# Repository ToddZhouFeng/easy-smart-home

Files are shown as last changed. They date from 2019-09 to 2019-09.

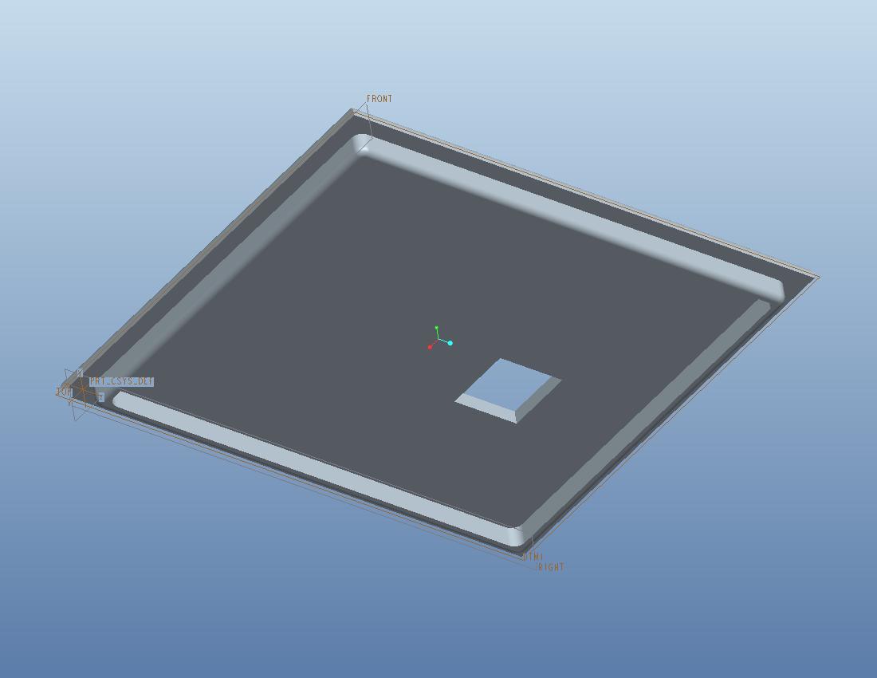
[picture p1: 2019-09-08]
example/auto AC remote control/3D model/cup/cup.jpg

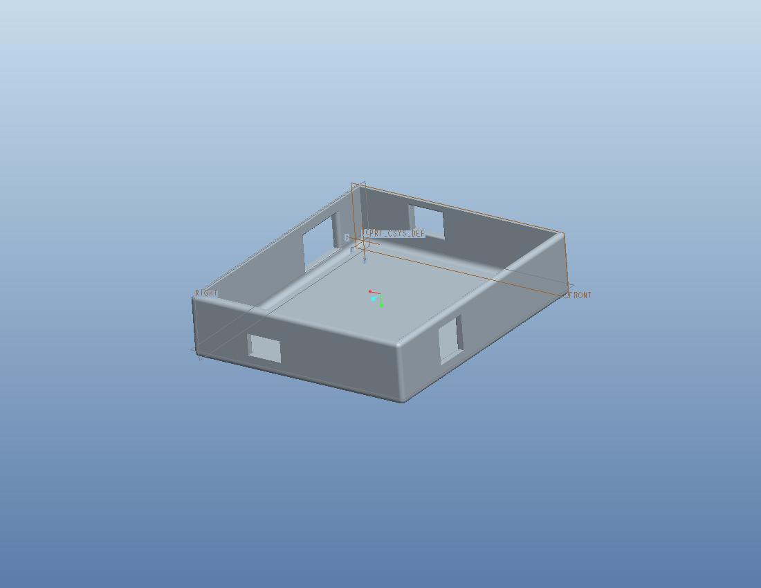
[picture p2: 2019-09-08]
example/auto AC remote control/3D model/shell/shell.jpg

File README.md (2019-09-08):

# easy-smart-home 轻智居
 This project aims to provide an easy solution for setting up  smart home in a affordable price.

该项目致力于提供便宜且易于设置的智能家居解决方案。

**Supported Device :**(for now)

**支持设备：**（目前）

* Arduino

# Structure 框架

* **Definition:**

  * **Master**：device that **can send instruction**

    **主机**：**可发送**指令的设备

  * **Slave**：device that **can's send instruction** but can receives instruction  

    **从机**：**不可发送**指令的设备，但可接收指令的设备

* **Single Line 单线：**

（如果显示不了，请前往[toddzhoufeng.github.io](https://toddzhoufeng.github.io)）

单主机单从机：

~~~sequence
Title: One Master One Slave
Master->Slave: Control
Slave-->Furniture: Control
~~~

* **Multiple Line 多线：**

单主机多从机：

```sequence
Title: One Master Multiple Slaves
Master->Slave1: Control
Master->Slave2: Control
Master->Slave3: Control
Slave3-->Furniture: Control
Slave2-->Furniture: Control
Slave1-->Furniture: Control 
```

多主机单从机：

```sequence
Title: Multiple Masters One Slave

participant Master1
participant Master2

Master1->Slave: Control
Master2->Slave: Control
Slave-->Furniture: Control
```

多主机多从机：

```sequence
Title: Multiple Masters Multiple Slave

participant Master1
participant Master2

Master1->Slave1: Control
Master2->Slave1: Control
Master1->Slave2: Control

Master2->Slave2: Control
Slave1-->Furniture: Control
Slave2-->Furniture: Control
```

# IR Protocol 红外编码

红外接收相比于蓝牙和网络的优势在于：

* 价格更便宜：红外接收管的价格为￥0.2/个
* 使用的引脚更少：仅需要1个
* 耗电量更小
* 等等

缺点在于：

* 对指向有一定要求
* 要求设备有开孔
* 无法做到远程操控
* 等等

目前来讲，红外比较适合受到自然条件（光、温）影响的智能设备，比如灯、窗帘、空调等，因为这些设备的位置比较固定，并且对远程操控的需求较小。

对于空调、电视一类的可受红外控制的设备，则采用厂家的编码协议；对于无红外的设备，则需要定义新的编码协议。新协议的目标如下：

1. 尽可能但又有区别地兼容现有的红外编码协议（如 NEC  以及 常见电器设备的红外编码协议）

2. 支持多种信息交换方式，比如单播（unicast）、多播（multicast）、广播（broadcast）
    单播（unicast） 
    多播（multicast）

  广播（broadcast）

3. 尽可能减小信号失真的危害
4. 有一定的加密能力 
5. 易于编程与理解

定义 0、1 编码如图：



一个完整的编码由以下5部分组成：

## 起始位

9ms 高 4.5ms 低

## 主机地址

8位主机类型码 + 8位地址

## 加密位

16位的加密

## 重复起始位/从机地址/数据

重复起始位：9ms 高 4.5ms 低

从机地址：8位地址 + 8位地址的反码，对于长度超出8位的地址，可以将反码也用为地址

数据：8位数据+8位数据的反码，对于长度超出8位的数据，可以将反码也用为数据



这一部分是为了与NEC协议兼容。

## 终止位

 15ms 高

> Inspired by TCP/IP
>
> 受TCP/IP启发

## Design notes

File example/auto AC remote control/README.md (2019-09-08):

自动空调调节
======
&emsp;&emsp;从温湿度传感器中获取数据，再通过红外发射管遥控空调，从而保持在睡觉时空调温度达到舒适状态。

```flow
st=>start: 开机
op=>operation: 每隔1min获取温度
cond=>condition: 预测是否太冷
high=>operation: 调低温度或保持不变
low=>operation: 调高温度
low_cond=>condition: 是否到最高
st->op->cond
cond(no)->high
high->op
cond(yes)->low(left)->opxxxxxxxxxx st=>start: 开机op=>operation: 每隔1min获取温度cond=>condition: 预测是否太冷high=>operation: 调低温度或保持不变low=>operation: 调高温度low_cond=>condition: 是否到最高st->op->condcond(no)->highhigh->opcond(yes)->low(left)->opst=>start: 开始op1=>operation: 获取数据op2=>operation: 比较op3=>operation: 调节ed=>end: 结束st->op1->op2->op3->edop3->op1flow
```

&emsp;&emsp;其中，获取数据部分不仅仅是获取传感器数据，而是根据最近几次的数据来判断将来的温湿度，从而在达到目标前提前调节。

&emsp;&emsp;由于是针对睡觉时的温度调节，所以采取宁愿太热也不会太冷。

# 零件

* Arduino nano
* 红外发射管
* 电池
* 充电板
* 开关

# 程序

## 红外发射部分

关于红外遥控的原理在此不再细讲，只大概讲一下如何获取编码：

1. 利用 IRremote 的 Example ：IRrecvDumpV2 获取数据（格式为数组）
2. 将数据利用 `irsend.sendRaw(irSignal, 199, khz);` 发送，其中，irSignal 为获取的数据，199 为数据长度，khz 为频率，一般为 38kHz

下面记录一下美的空调的编码（遥控器型号： RN51F/BG）

* 开机（制冷，20，中风）

  ```c
  unsigned int  rawData[199] = {4400,4400, 600,1550, 600,500, 600,1550, 600,1600, 550,500, 600,500, 600,1550, 600,500, 600,500, 550,1600, 600,500, 550,500, 600,1600, 600,1550, 600,500, 600,1550, 600,500, 600,1550, 600,500, 600,1550, 600,1600, 550,1600, 600,1550, 600,1600, 600,1550, 600,500, 550,1600, 600,500, 600,450, 600,500, 600,500, 600,450, 600,500, 600,500, 600,1550, 600,500, 600,500, 550,500, 600,500, 600,500, 550,1600, 600,1550, 600,500, 600,1550, 600,1600, 550,1600, 600,1550, 600,1600, 600,5150, 4500,4350, 600,1550, 600,500, 600,1550, 600,1600, 600,450, 600,500, 600,1550, 600,500, 600,500, 600,1550, 600,500, 600,500, 550,1600, 600,1550, 600,500, 600,1550, 600,500, 600,1550, 600,500, 600,1550, 600,1600, 600,1550, 600,1550, 600,1600, 600,1550, 600,500, 600,1550, 600,500, 600,500, 550,500, 600,500, 600,500, 600,450, 600,500, 600,1550, 600,500, 600,500, 600,450, 600,500, 600,500, 600,1550, 600,1600, 550,500, 600,1600, 550,1600, 600,1550, 600,1600, 550,1600, 600};  // 8a0820a222aa88000800a2aae8a0820a222aa88000800a2aa
  ```

* 关机

  ```c
  unsigned int  rawData[199] = {4450,4350, 600,1600, 600,450, 600,1600, 600,1550, 600,500, 600,500, 550,1600, 600,500, 550,500, 600,1600, 550,500, 600,500, 600,1550, 600,1600, 550,500, 600,1600, 600,450, 600,1600, 600,1550, 600,1600, 550,1600, 650,450, 600,1550, 600,1550, 600,1600, 550,500, 600,500, 600,500, 600,450, 600,1600, 550,500, 600,500, 600,1550, 600,1600, 600,1550, 600,500, 600,500, 550,500, 600,500, 600,500, 550,500, 600,500, 650,450, 600,1550, 600,1550, 600,1600, 650,1500, 600,1550, 600,5200, 4450,4400, 550,1600, 600,500, 600,1550, 600,1550, 600,500, 600,500, 600,1550, 600,500, 600,450, 600,1600, 600,500, 550,500, 600,1600, 550,1600, 600,500, 600,1550, 600,500, 550,1600, 600,1550, 600,1600, 550,1600, 600,500, 600,1550, 600,1600, 550,1600, 600,500, 550,500, 600,500, 600,500, 550,1600, 600,500, 550,500, 600,1600, 550,1600, 600,1550, 600,500, 600,500, 550,500, 600,500, 600,500, 600,450, 600,500, 600,500, 600,1550, 600,1600, 550,1600, 600,1550, 600,1600, 550};  // SAMSUNG B24D7B84
  ```

* 在制冷中风下，各温度的编码：

  17

  ```c
  unsigned int  rawData[199] = {4400,4400, 600,1550, 600,500, 600,1550, 600,1600, 550,550, 550,500, 600,1550, 600,550, 550,500, 600,1550, 600,500, 550,550, 550,1600, 600,1600, 550,500, 600,1550, 600,500, 600,1550, 600,500, 600,1550, 600,1600, 550,1600, 600,1550, 600,1600, 600,1550, 600,500, 550,1600, 600,500, 600,500, 550,550, 550,500, 600,500, 550,550, 550,500, 600,500, 550,550, 550,500, 600,500, 550,550, 550,500, 600,1600, 550,1600, 550,1600, 600,1550, 600,1600, 600,1550, 600,1550, 600,1600, 600,5150, 4500,4350, 600,1550, 600,550, 550,1550, 600,1600, 600,500, 550,550, 550,1600, 550,550, 550,500, 600,1550, 600,500, 600,500, 550,1600, 600,1550, 600,550, 550,1550, 600,550, 550,1550, 600,550, 550,1550, 600,1600, 600,1550, 600,1600, 550,1600, 600,1550, 600,500, 600,1550, 600,550, 550,500, 600,500, 550,550, 550,500, 550,550, 550,550, 550,500, 600,500, 550,550, 550,500, 600,500, 550,550, 550,1600, 550,1600, 600,1550, 600,1600, 600,1550, 600,1550, 600,1600, 600,1550, 600};  // 8a0820a222aa88000000aaaae8a0820a222aa88000000aaaa
  ```

  20

  ```c
  unsigned int  rawData[199] = {4450,4350, 600,1600, 550,500, 600,1600, 600,1550, 600,500, 600,450, 600,1600, 600,450, 600,500, 600,1600, 550,500, 600,500, 600,1550, 600,1600, 550,500, 600,1600, 600,450, 600,1600, 550,500, 600,1600, 600,1550, 600,1550, 600,1600, 600,1550, 600,1600, 550,500, 600,1600, 550,500, 600,500, 600,500, 550,500, 600,500, 600,500, 600,450, 600,1600, 550,500, 600,500, 600,500, 600,450, 600,500, 600,1550, 600,1600, 600,500, 550,1600, 600,1550, 600,1600, 550,1600, 600,1550, 600,5200, 4450,4400, 550,1600, 600,500, 550,1600, 600,1550, 600,500, 600,500, 550,1600, 600,500, 600,450, 600,1600, 600,500, 550,500, 600,1550, 600,1600, 600,500, 550,1600, 600,500, 550,1600, 600,500, 550,1600, 600,1550, 600,1600, 550,1600, 600,1550, 600,1600, 600,450, 600,1600, 600,450, 600,500, 600,500, 600,500, 550,500, 600,500, 600,500, 600,1550, 600,500, 550,500, 600,500, 600,500, 600,450, 600,1600, 550,1600, 600,500, 600,1550, 600,1550, 600,1600, 600,1550, 600,1600, 550};  // 8a0820a222aa88000800a2aae8a0820a222aa88000800a2aa
  ```

  23

  ```c
  unsigned int  rawData[199] = {4400,4400, 550,1600, 600,500, 550,1600, 600,1550, 600,500, 600,500, 600,1550, 600,500, 600,450, 600,1600, 600,450, 600,500, 600,1600, 550,1600, 600,500, 550,1600, 600,500, 550,1600, 600,500, 550,1600, 600,1550, 600,1600, 600,1550, 600,1550, 600,1600, 600,500, 550,1600, 600,500, 550,550, 550,500, 600,500, 550,500, 600,500, 600,1550, 600,500, 600,1550, 600,500, 600,500, 600,450, 600,500, 600,1550, 600,500, 600,1550, 600,500, 600,1600, 550,1600, 600,1550, 600,1600, 550,5200, 4500,4350, 600,1550, 600,500, 600,1550, 600,1600, 550,500, 600,500, 600,1550, 600,500, 600,500, 550,1600, 600,500, 600,450, 600,1600, 550,1600, 600,500, 600,1550, 600,500, 600,1550, 600,500, 600,1550, 600,1600, 550,1600, 600,1550, 600,1600, 550,1600, 600,500, 600,1550, 600,500, 600,450, 600,500, 600,500, 600,450, 600,500, 600,1600, 550,500, 600,1600, 550,500, 600,500, 600,500, 550,500, 600,1600, 550,500, 600,1600, 600,450, 600,1600, 600,1550, 600,1550, 600,1600, 600};  // 8a0820a222aa8800220088aae8a0820a222aa8800220088aa
  ```

  27

  ```c
  unsigned int  rawData[199] = {4450,4350, 600,1550, 600,550, 550,1550, 600,1600, 600,500, 550,550, 550,1550, 600,550, 550,500, 600,1550, 600,500, 600,500, 550,1600, 600,1550, 600,500, 600,1550, 600,500, 600,1550, 600,550, 550,1550, 600,1600, 600,1550, 600,1550, 600,1600, 600,1550, 600,500, 600,1550, 600,500, 600,500, 550,550, 550,500, 600,500, 550,1600, 600,500, 600,500, 550,1600, 550,550, 550,550, 550,500, 600,500, 550,550, 550,1550, 600,1600, 600,500, 550,1600, 600,1550, 600,1600, 550,1600, 600,5200, 4450,4350, 600,1600, 550,550, 550,1600, 550,1600, 600,500, 550,550, 550,1600, 600,500, 550,550, 550,1550, 600,550, 550,500, 600,1550, 600,1550, 600,550, 550,1600, 550,550, 550,1600, 550,550, 550,1600, 550,1600, 600,1550, 600,1600, 600,1550, 600,1550, 600,550, 550,1550, 600,550, 550,500, 600,500, 550,550, 550,500, 600,1550, 600,500, 600,500, 550,1600, 600,500, 550,550, 550,550, 550,500, 550,550, 550,1600, 600,1550, 600,500, 600,1550, 600,1550, 600,1600, 600,1550, 600};  // 8a0820a222aa8800820028aae8a0820a222aa8800820028aa
  ```

  30

  ```c
  unsigned int  rawData[199] = {4450,4350, 600,1550, 600,500, 600,1550, 600,1600, 550,500, 600,500, 600,1550, 600,500, 600,500, 600,1550, 600,500, 600,500, 550,1600, 600,1550, 600,500, 600,1550, 600,500, 600,1550, 600,500, 600,1550, 600,1600, 600,1550, 600,1550, 600,1600, 600,1550, 600,500, 600,1550, 600,500, 600,500, 550,500, 600,500, 600,500, 550,1600, 600,500, 600,1550, 600,1550, 600,500, 600,500, 600,450, 600,500, 600,500, 600,1550, 600,500, 600,500, 550,1600, 600,1550, 600,1600, 600,1550, 600,5200, 4450,4350, 600,1600, 550,500, 650,1550, 550,1600, 600,500, 550,500, 600,1600, 600,450, 600,500, 600,1550, 600,500, 600,500, 600,1550, 600,1550, 600,500, 600,1550, 600,500, 600,1600, 550,500, 600,1600, 600,1550, 600,1550, 600,1600, 600,1550, 600,1550, 600,500, 600,1550, 600,500, 600,500, 600,450, 600,500, 600,500, 600,1550, 600,500, 600,1550, 600,1600, 600,450, 600,500, 600,500, 550,500, 600,500, 600,1550, 600,500, 600,500, 550,1600, 600,1550, 600,1600, 600,1550, 600};  // 8a0820a222aa88008a0020aae8a0820a222aa88008a0020aa
  ```

仔细观察可以发现，所有编码前99与后99是相同的，所以只需要储存前100个编码即可。但这对储存的要求一人很高。目前来看并没有一种有效的方法压缩储存。尝试了多种简化方法，均以失败告终。未来尝试对不同编码进行对比，找出个部分的意思。

## 从DHT12获取数据

```c
#include <Wire.h>

void setup() {
  Serial.begin(9600);
  Serial.println("Start");
  Wire.begin();
}

void loop() {
  Wire.beginTransmission(0x5C); //DHT12 的地址
  Wire.write(0); //向 DHT12 请求数据
  Wire.endTransmission();
  int bytes = Wire.requestFrom(0x5C, 5);
  uint8_t bits[5];
  for(int i=0;i<bytes;++i){
    bits[i]=Wire.read();
  }
  float humidity = bits[0] + bits[1]*0.1;
  float temperature = bits[2] + (bits[3] & 0x7F) * 0.1;
  if(bits[3] & 0x80){
    temperature = -temperature;
  }
  uint8_t checksum=bits[0]+bits[1]+bits[2]+bits[3];
  if(bits[4] != checksum){
    Serial.println("Error");
  }
  else{
    Serial.print("DHT12, \t");
    Serial.print(humidity, 1);
    Serial.print(",\t");
    Serial.println(temperature, 1);
  }
  delay(1000);
}
```

# 回归预测

由实验数据（temperature data and fitting.xlsx）可以看出，开空调后，房间内的温度大体上呈对数形，但由于 Arduino 的数学运算并不强，而且温度数据可看作分段线性，故使用分段线性回归。

```c

int interval = 10; //预测的间隔时间
float aver_x = 5.5; //从1到interval的平均值
float a,b;//回归方程的参数
float y[] = {10, 9, 8, 7, 6, 5, 4, 3, 2, 1};//数量要等于interval

int get_ab(float y[]) {
  float aver_y = 0;
  for (int i = interval - 1; i >= 0; --i) {
    aver_y += y[i];
  }
  aver_y /= interval;

  float b_frac_up = 0;
  for (int i = interval; i; --i) {
    b_frac_up += (i * y[i - 1]);
  }
  b_frac_up-=(interval*aver_x*aver_y);

  float b_frac_down = 0;
  for(int i=interval;i;--i){
    b_frac_down += (i*i);
  }
  b_frac_down-=(interval*aver_x*aver_x);

  if(b_frac_down){
    b=b_frac_up/b_frac_down;
  }
  else return 0;

  a=aver_y-b*aver_x;
  return 1;
}

void setup() {
  // put your setup code here, to run once:
  Serial.begin(9600);
  get_ab(y);
  Serial.println(a);
  Serial.println(b);
}

void loop() {
  // put your main code here, to run repeatedly:
}
```

下面是利用10次数据（间隔1分钟）来预测10分钟后的温度的实测：

```c
20:13:58.428 -> Start
20:14:08.461 -> 28.7,28.7,28.7,28.7,28.7,28.7,28.7,28.8,28.7,28.7,
20:14:08.497 -> Temperature:28.8
20:14:08.637 -> send open

20:15:08.696 -> 28.7,28.7,28.7,28.7,28.7,28.7,28.8,28.7,28.7,28.7,
20:15:08.731 -> Temperature:28.7
20:16:08.739 -> 28.7,28.7,28.7,28.7,28.7,28.8,28.7,28.7,28.7,28.7,
20:16:08.774 -> Temperature:28.7
20:17:08.810 -> 28.7,28.7,28.7,28.7,28.8,28.7,28.7,28.7,28.7,28.7,
20:17:08.844 -> Temperature:28.7
20:18:08.825 -> 28.7,28.7,28.7,28.8,28.7,28.7,28.7,28.7,28.7,28.6,
20:18:08.863 -> Temperature:28.6
20:19:08.885 -> 28.7,28.7,28.8,28.7,28.7,28.7,28.7,28.7,28.6,28.6,
20:19:08.919 -> Temperature:28.5
20:20:08.947 -> 28.7,28.8,28.7,28.7,28.7,28.7,28.7,28.6,28.6,28.6,
20:20:08.983 -> Temperature:28.4
20:21:09.002 -> 28.8,28.7,28.7,28.7,28.7,28.7,28.6,28.6,28.6,28.5,
20:21:09.002 -> Temperature:28.3
20:22:09.039 -> 28.7,28.7,28.7,28.7,28.7,28.6,28.6,28.6,28.5,28.4,
20:22:09.075 -> Temperature:28.2
20:23:09.087 -> 28.7,28.7,28.7,28.7,28.6,28.6,28.6,28.5,28.4,28.3,
20:23:09.125 -> Temperature:28.0
    
20:23:09.265 -> send 30
20:24:09.308 -> 28.7,28.7,28.7,28.6,28.6,28.6,28.5,28.4,28.3,28.3,
20:24:09.342 -> Temperature:27.8
20:25:09.376 -> 28.7,28.7,28.6,28.6,28.6,28.5,28.4,28.3,28.3,28.3,
20:25:09.409 -> Temperature:27.7
20:26:09.417 -> 28.7,28.6,28.6,28.6,28.5,28.4,28.3,28.3,28.3,28.3,
20:26:09.453 -> Temperature:27.7
20:27:09.463 -> 28.6,28.6,28.6,28.5,28.4,28.3,28.3,28.3,28.3,28.2,
20:27:09.497 -> Temperature:27.7
20:28:09.517 -> 28.6,28.6,28.5,28.4,28.3,28.3,28.3,28.3,28.2,28.2,
20:28:09.552 -> Temperature:27.7
20:29:09.564 -> 28.6,28.5,28.4,28.3,28.3,28.3,28.3,28.2,28.2,28.1,
20:29:09.600 -> Temperature:27.7
20:30:09.598 -> 28.5,28.4,28.3,28.3,28.3,28.3,28.2,28.2,28.1,28.2,
20:30:09.735 -> Temperature:27.8
20:31:09.632 -> 28.4,28.3,28.3,28.3,28.3,28.2,28.2,28.1,28.2,28.2,
20:31:09.668 -> Temperature:27.9
20:32:09.683 -> 28.3,28.3,28.3,28.3,28.2,28.2,28.1,28.2,28.2,28.1,
20:32:09.718 -> Temperature:27.9
20:33:09.745 -> 28.3,28.3,28.3,28.2,28.2,28.1,28.2,28.2,28.1,28.2,
20:33:09.779 -> Temperature:28.0
20:34:09.803 -> 28.3,28.3,28.2,28.2,28.1,28.2,28.2,28.1,28.2,28.2,
20:34:09.840 -> Temperature:28.0
    
20:34:09.946 -> send open
20:35:10.041 -> 28.3,28.2,28.2,28.1,28.2,28.2,28.1,28.2,28.2,28.2,
20:35:10.041 -> Temperature:28.1
20:36:10.085 -> 28.2,28.2,28.1,28.2,28.2,28.1,28.2,28.2,28.2,28.2,
20:36:10.120 -> Temperature:28.2
20:37:10.117 -> 28.2,28.1,28.2,28.2,28.1,28.2,28.2,28.2,28.2,28.2,
20:37:10.151 -> Temperature:28.3
20:38:10.163 -> 28.1,28.2,28.2,28.1,28.2,28.2,28.2,28.2,28.2,28.2,
20:38:10.196 -> Temperature:28.3
20:39:10.210 -> 28.2,28.2,28.1,28.2,28.2,28.2,28.2,28.2,28.2,28.1,
20:39:10.245 -> Temperature:28.1
20:40:10.275 -> 28.2,28.1,28.2,28.2,28.2,28.2,28.2,28.2,28.1,28.0,
20:40:10.310 -> Temperature:28.0
20:41:10.325 -> 28.1,28.2,28.2,28.2,28.2,28.2,28.2,28.1,28.0,28.0,
20:41:10.325 -> Temperature:27.9
    
20:41:10.467 -> send 30
20:42:10.556 -> 28.2,28.2,28.2,28.2,28.2,28.2,28.1,28.0,28.0,28.0,
20:42:10.592 -> Temperature:27.7
20:43:10.600 -> 28.2,28.2,28.2,28.2,28.2,28.1,28.0,28.0,28.0,28.0,
20:43:10.683 -> Temperature:27.7
20:44:10.646 -> 28.2,28.2,28.2,28.2,28.1,28.0,28.0,28.0,28.0,27.9,
20:44:10.681 -> Temperature:27.6
20:45:10.674 -> 28.2,28.2,28.2,28.1,28.0,28.0,28.0,28.0,27.9,27.9,
20:45:10.710 -> Temperature:27.5
20:46:10.732 -> 28.2,28.2,28.1,28.0,28.0,28.0,28.0,27.9,27.9,27.8,
20:46:10.769 -> Temperature:27.4
20:47:10.951 -> 28.2,28.1,28.0,28.0,28.0,28.0,27.9,27.9,27.8,27.9,
20:47:10.951 -> Temperature:27.5
20:48:10.833 -> 28.1,28.0,28.0,28.0,28.0,27.9,27.9,27.8,27.9,28.0,
20:48:10.867 -> Temperature:27.7
20:49:10.864 -> 28.0,28.0,28.0,28.0,27.9,27.9,27.8,27.9,28.0,28.0,
20:49:10.900 -> Temperature:27.9
20:50:10.905 -> 28.0,28.0,28.0,27.9,27.9,27.8,27.9,28.0,28.0,28.0,
20:50:10.940 -> Temperature:27.9
20:51:10.958 -> 28.0,28.0,27.9,27.9,27.8,27.9,28.0,28.0,28.0,28.0,
20:51:10.993 -> Temperature:28.0
    
20:51:11.135 -> send open
20:52:11.191 -> 28.0,27.9,27.9,27.8,27.9,28.0,28.0,28.0,28.0,28.1,
20:52:11.226 -> Temperature:28.2
20:53:11.243 -> 27.9,27.9,27.8,27.9,28.0,28.0,28.0,28.0,28.1,28.2,
20:53:11.280 -> Temperature:28.5
20:54:11.294 -> 27.9,27.8,27.9,28.0,28.0,28.0,28.0,28.1,28.2,28.1,
20:54:11.331 -> Temperature:28.5
20:55:11.334 -> 27.8,27.9,28.0,28.0,28.0,28.0,28.1,28.2,28.1,28.2,
20:55:11.369 -> Temperature:28.6
20:56:11.380 -> 27.9,28.0,28.0,28.0,28.0,28.1,28.2,28.1,28.2,28.2,
20:56:11.414 -> Temperature:28.5
20:57:11.452 -> 28.0,28.0,28.0,28.0,28.1,28.2,28.1,28.2,28.2,28.1,
20:57:11.488 -> Temperature:28.4
20:58:11.488 -> 28.0,28.0,28.0,28.1,28.2,28.1,28.2,28.2,28.1,28.1,
20:58:11.522 -> Temperature:28.3
20:59:11.550 -> 28.0,28.0,28.1,28.2,28.1,28.2,28.2,28.1,28.1,28.1,
20:59:11.584 -> Temperature:28.3
21:00:11.569 -> 28.0,28.1,28.2,28.1,28.2,28.2,28.1,28.1,28.1,28.0,
21:00:11.603 -> Temperature:28.1
21:01:11.639 -> 28.1,28.2,28.1,28.2,28.2,28.1,28.1,28.1,28.0,28.0,
21:01:11.673 -> Temperature:27.9
    
21:01:11.813 -> send 30
21:02:11.874 -> 28.2,28.1,28.2,28.2,28.1,28.1,28.1,28.0,28.0,28.0,
21:02:11.910 -> Temperature:27.8
21:03:11.919 -> 28.1,28.2,28.2,28.1,28.1,28.1,28.0,28.0,28.0,27.9,
21:03:11.953 -> Temperature:27.7
21:04:11.961 -> 28.2,28.2,28.1,28.1,28.1,28.0,28.0,28.0,27.9,27.9,
21:04:11.995 -> Temperature:27.5
21:05:11.992 -> 28.2,28.1,28.1,28.1,28.0,28.0,28.0,27.9,27.9,27.9,
21:05:12.028 -> Temperature:27.5
21:06:12.047 -> 28.1,28.1,28.1,28.0,28.0,28.0,27.9,27.9,27.9,27.9,
21:06:12.080 -> Temperature:27.6
21:07:12.085 -> 28.1,28.1,28.0,28.0,28.0,27.9,27.9,27.9,27.9,27.9,
21:07:12.123 -> Temperature:27.6
21:08:12.138 -> 28.1,28.0,28.0,28.0,27.9,27.9,27.9,27.9,27.9,27.9,
21:08:12.171 -> Temperature:27.7
21:09:12.181 -> 28.0,28.0,28.0,27.9,27.9,27.9,27.9,27.9,27.9,27.9,
21:09:12.217 -> Temperature:27.7
21:10:12.249 -> 28.0,28.0,27.9,27.9,27.9,27.9,27.9,27.9,27.9,27.9,
21:10:12.284 -> Temperature:27.8
21:11:12.280 -> 28.0,27.9,27.9,27.9,27.9,27.9,27.9,27.9,27.9,28.0,
21:11:12.314 -> Temperature:27.9
21:12:12.336 -> 27.9,27.9,27.9,27.9,27.9,27.9,27.9,27.9,28.0,28.0,
21:12:12.370 -> Temperature:28.1
    
21:12:12.793 -> send open
21:13:12.556 -> 27.9,27.9,27.9,27.9,27.9,27.9,27.9,28.0,28.0,28.0,
21:13:12.593 -> Temperature:28.1
21:14:12.625 -> 27.9,27.9,27.9,27.9,27.9,27.9,28.0,28.0,28.0,28.0,
21:14:12.658 -> Temperature:28.2
21:15:12.682 -> 27.9,27.9,27.9,27.9,27.9,28.0,28.0,28.0,28.0,28.1,
21:15:12.717 -> Temperature:28.3
21:16:12.703 -> 27.9,27.9,27.9,27.9,28.0,28.0,28.0,28.0,28.1,28.1,
21:16:12.738 -> Temperature:28.3
21:17:12.750 -> 27.9,27.9,27.9,28.0,28.0,28.0,28.0,28.1,28.1,28.0,
21:17:12.787 -> Temperature:28.3
21:18:12.813 -> 27.9,27.9,28.0,28.0,28.0,28.0,28.1,28.1,28.0,28.0,
21:18:12.846 -> Temperature:28.2
21:19:12.848 -> 27.9,28.0,28.0,28.0,28.0,28.1,28.1,28.0,28.0,28.0,
21:19:12.883 -> Temperature:28.1
21:20:12.909 -> 28.0,28.0,28.0,28.0,28.1,28.1,28.0,28.0,28.0,28.0,
21:20:12.945 -> Temperature:28.0
21:21:12.952 -> 28.0,28.0,28.0,28.1,28.1,28.0,28.0,28.0,28.0,28.0,
21:21:12.986 -> Temperature:28.0
    
21:21:13.127 -> send 30
21:22:13.191 -> 28.0,28.0,28.1,28.1,28.0,28.0,28.0,28.0,28.0,27.9,
21:22:13.228 -> Temperature:27.9
21:23:13.225 -> 28.0,28.1,28.1,28.0,28.0,28.0,28.0,28.0,27.9,27.8,
21:23:13.261 -> Temperature:27.7
21:24:13.286 -> 28.1,28.1,28.0,28.0,28.0,28.0,28.0,27.9,27.8,27.9,
21:24:13.392 -> Temperature:27.6
21:25:13.337 -> 28.1,28.0,28.0,28.0,28.0,28.0,27.9,27.8,27.9,27.9,
21:25:13.372 -> Temperature:27.6
21:26:13.378 -> 28.0,28.0,28.0,28.0,28.0,27.9,27.8,27.9,27.9,27.8,
21:26:13.413 -> Temperature:27.6
21:27:13.418 -> 28.0,28.0,28.0,28.0,27.9,27.8,27.9,27.9,27.8,27.8,
21:27:13.455 -> Temperature:27.5
21:28:13.474 -> 28.0,28.0,28.0,27.9,27.8,27.9,27.9,27.8,27.8,27.8,
21:28:13.510 -> Temperature:27.5
21:29:13.525 -> 28.0,28.0,27.9,27.8,27.9,27.9,27.8,27.8,27.8,27.8,
21:29:13.559 -> Temperature:27.5
21:30:13.569 -> 28.0,27.9,27.8,27.9,27.9,27.8,27.8,27.8,27.8,27.9,
21:30:13.605 -> Temperature:27.7
21:31:13.595 -> 27.9,27.8,27.9,27.9,27.8,27.8,27.8,27.8,27.9,27.9,
21:31:13.630 -> Temperature:27.8
21:32:13.655 -> 27.8,27.9,27.9,27.8,27.8,27.8,27.8,27.9,27.9,28.0,
21:32:13.688 -> Temperature:28.0
    
21:32:13.829 -> send open
21:33:13.878 -> 27.9,27.9,27.8,27.8,27.8,27.8,27.9,27.9,28.0,28.0,
21:33:13.914 -> Temperature:28.1
21:34:13.942 -> 27.9,27.8,27.8,27.8,27.8,27.9,27.9,28.0,28.0,28.0,
21:34:13.976 -> Temperature:28.2
21:35:13.979 -> 27.8,27.8,27.8,27.8,27.9,27.9,28.0,28.0,28.0,28.0,
21:35:14.015 -> Temperature:28.3
21:36:14.026 -> 27.8,27.8,27.8,27.9,27.9,28.0,28.0,28.0,28.0,28.0,
21:36:14.063 -> Temperature:28.3
21:37:14.072 -> 27.8,27.8,27.9,27.9,28.0,28.0,28.0,28.0,28.0,28.0,
21:37:14.106 -> Temperature:28.3
21:38:14.130 -> 27.8,27.9,27.9,28.0,28.0,28.0,28.0,28.0,28.0,28.0,
21:38:14.164 -> Temperature:28.2
21:39:14.191 -> 27.9,27.9,28.0,28.0,28.0,28.0,28.0,28.0,28.0,27.9,
21:39:14.226 -> Temperature:28.0
21:40:14.228 -> 27.9,28.0,28.0,28.0,28.0,28.0,28.0,28.0,27.9,27.8,
21:40:14.264 -> Temperature:27.8
    
21:40:14.403 -> send 30
21:41:14.441 -> 28.0,28.0,28.0,28.0,28.0,28.0,28.0,27.9,27.8,27.9,
21:41:14.518 -> Temperature:27.7
21:42:14.508 -> 28.0,28.0,28.0,28.0,28.0,28.0,27.9,27.8,27.9,27.8,
21:42:14.541 -> Temperature:27.6
21:43:14.538 -> 28.0,28.0,28.0,28.0,28.0,27.9,27.8,27.9,27.8,27.7,
21:43:14.575 -> Temperature:27.4
21:44:14.610 -> 28.0,28.0,28.0,28.0,27.9,27.8,27.9,27.8,27.7,27.7,
21:44:14.644 -> Temperature:27.3
21:45:14.644 -> 28.0,28.0,28.0,27.9,27.8,27.9,27.8,27.7,27.7,27.6,
21:45:14.679 -> Temperature:27.2
21:46:14.696 -> 28.0,28.0,27.9,27.8,27.9,27.8,27.7,27.7,27.6,27.6,
21:46:14.731 -> Temperature:27.1
21:47:14.751 -> 28.0,27.9,27.8,27.9,27.8,27.7,27.7,27.6,27.6,27.5,
21:47:14.785 -> Temperature:27.0
21:48:14.792 -> 27.9,27.8,27.9,27.8,27.7,27.7,27.6,27.6,27.5,27.5,
21:48:15.075 -> Temperature:27.0
21:49:14.834 -> 27.8,27.9,27.8,27.7,27.7,27.6,27.6,27.5,27.5,27.5,
21:49:14.871 -> Temperature:27.0
21:50:14.884 -> 27.9,27.8,27.7,27.7,27.6,27.6,27.5,27.5,27.5,27.5,
21:50:14.919 -> Temperature:27.0
21:51:14.942 -> 27.8,27.7,27.7,27.6,27.6,27.5,27.5,27.5,27.5,27.5,
21:51:14.977 -> Temperature:27.1
21:52:14.987 -> 27.7,27.7,27.6,27.6,27.5,27.5,27.5,27.5,27.5,27.5,
21:52:15.024 -> Temperature:27.2
21:53:15.023 -> 27.7,27.6,27.6,27.5,27.5,27.5,27.5,27.5,27.5,27.3,
21:53:15.058 -> Temperature:27.1
21:54:15.084 -> 27.6,27.6,27.5,27.5,27.5,27.5,27.5,27.5,27.3,27.2,
21:54:15.118 -> Temperature:27.0
21:55:15.117 -> 27.6,27.5,27.5,27.5,27.5,27.5,27.5,27.3,27.2,27.2,
21:55:15.150 -> Temperature:26.8
21:56:15.175 -> 27.5,27.5,27.5,27.5,27.5,27.5,27.3,27.2,27.2,27.2,
21:56:15.211 -> Temperature:26.8
21:57:15.216 -> 27.5,27.5,27.5,27.5,27.5,27.3,27.2,27.2,27.2,27.2,
21:57:15.250 -> Temperature:26.7
21:58:15.273 -> 27.5,27.5,27.5,27.5,27.3,27.2,27.2,27.2,27.2,27.1,
21:58:15.273 -> Temperature:26.6
21:59:15.310 -> 27.5,27.5,27.5,27.3,27.2,27.2,27.2,27.2,27.1,27.0,
21:59:15.346 -> Temperature:26.5
22:00:15.354 -> 27.5,27.5,27.3,27.2,27.2,27.2,27.2,27.1,27.0,27.0,
22:00:15.388 -> Temperature:26.4
22:01:15.388 -> 27.5,27.3,27.2,27.2,27.2,27.2,27.1,27.0,27.0,27.0,
22:01:15.423 -> Temperature:26.5
22:02:15.439 -> 27.3,27.2,27.2,27.2,27.2,27.1,27.0,27.0,27.0,26.9,
22:02:15.474 -> Temperature:26.5
22:03:15.484 -> 27.2,27.2,27.2,27.2,27.1,27.0,27.0,27.0,26.9,26.9,
22:03:15.522 -> Temperature:26.5
22:04:15.530 -> 27.2,27.2,27.2,27.1,27.0,27.0,27.0,26.9,26.9,26.9,
22:04:15.566 -> Temperature:26.5
```

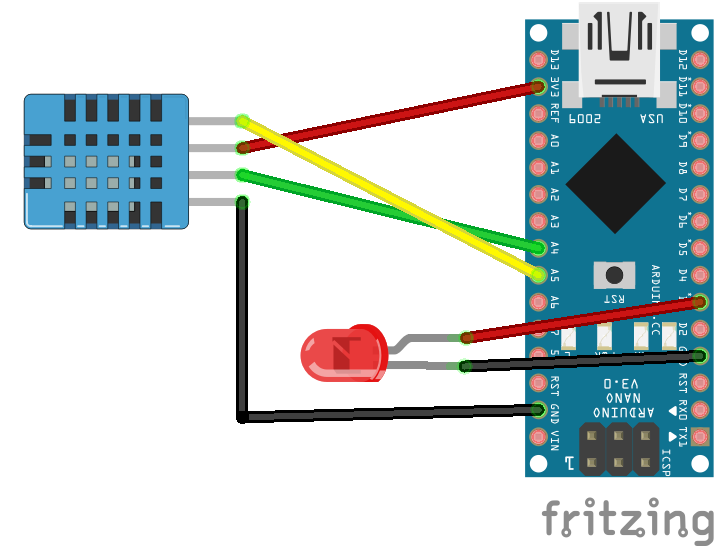
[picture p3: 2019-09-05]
example/auto AC remote control/wire connection.png

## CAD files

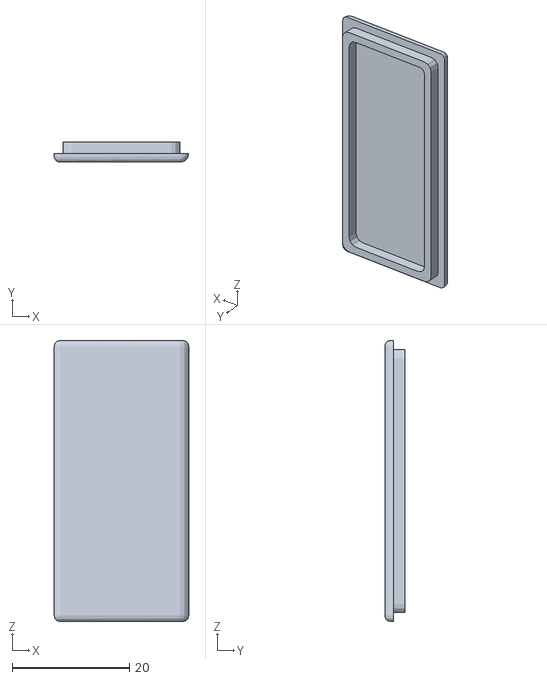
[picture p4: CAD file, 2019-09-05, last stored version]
example/auto AC remote control/3D model/cup/cup2.stl
23.0 x 3.50 x 48.0

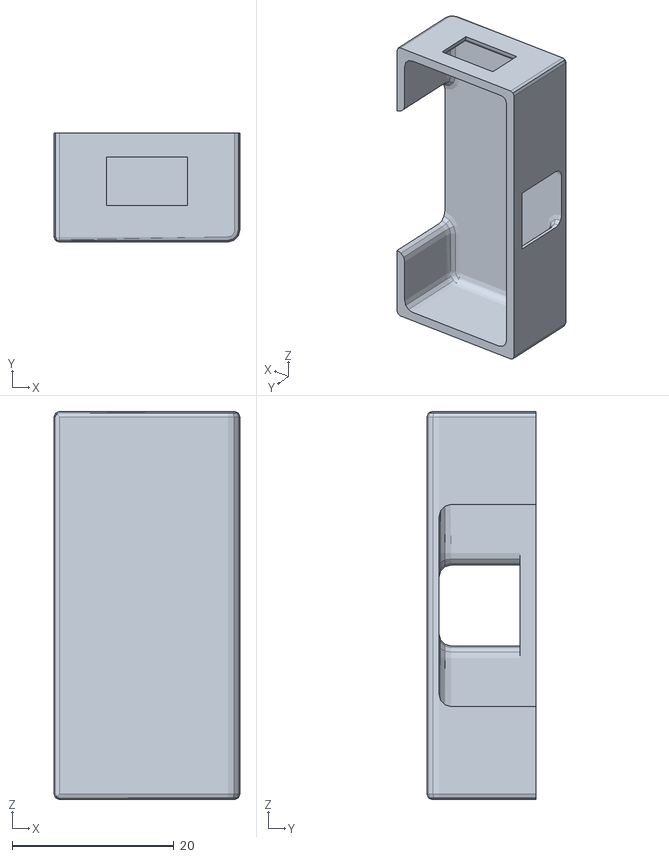
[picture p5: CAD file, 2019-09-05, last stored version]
example/auto AC remote control/3D model/shell/shell2.stl
23.0 x 13.5 x 48.0

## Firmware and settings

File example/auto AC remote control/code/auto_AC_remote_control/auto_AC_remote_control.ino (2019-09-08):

#include <Wire.h>
#include <IRremote.h>

int target_temp = 24; //目标温度，必须是二十几，人体最舒适的温度为18~24
//红外编码部分开始//
IRsend irsend;
unsigned int IR20high[100] = {4450, 4350, 600, 1550, 650, 450, 600, 1550, 650, 1550, 600, 450, 650, 450, 600, 1550, 600, 500, 600, 500, 600, 1550, 600, 500, 550, 500, 650, 1550, 600, 1550, 600, 500, 600, 1550, 600, 500, 600, 450, 600, 1600, 550, 1600, 600, 1550, 600, 1600, 600, 1550, 600, 1550, 600, 1600, 600, 1550, 600, 500, 600, 450, 600, 500, 600, 500, 600, 500, 550, 500, 600, 500, 600, 500, 550, 1600, 600, 500, 550, 500, 600, 500, 600, 500, 550, 500, 600, 1600, 550, 1600, 600, 500, 600, 1550, 600, 1550, 600, 1600, 550, 1600, 600, 1550, 600, 5200}; //制冷 20 高风
unsigned int  IR25mid[100] = {4400, 4400, 600, 1550, 600, 500, 600, 1550, 600, 1550, 600, 500, 600, 500, 600, 1550, 600, 500, 600, 450, 600, 1600, 600, 450, 600, 500, 600, 1550, 600, 1600, 600, 450, 600, 1600, 600, 500, 550, 1600, 600, 500, 550, 1600, 600, 1550, 600, 1600, 550, 1600, 600, 1550, 600, 1600, 550, 500, 600, 1600, 550, 500, 600, 500, 600, 500, 550, 500, 600, 500, 600, 1550, 600, 1600, 550, 500, 600, 500, 600, 500, 550, 500, 600, 500, 600, 500, 550, 500, 600, 500, 600, 1550, 600, 1600, 600, 1550, 600, 1550, 600, 1600, 600, 1550, 600, 5200}; //制冷 25 中风
//unsigned int IR30mid[100] = {4400, 4400, 550, 1600, 600, 500, 550, 1600, 600, 1550, 600, 500, 600, 500, 600, 1550, 600, 500, 600, 450, 600, 1600, 600, 450, 600, 500, 600, 1550, 600, 1600, 600, 450, 600, 1600, 600, 450, 600, 1600, 550, 500, 600, 1600, 550, 1600, 600, 1550, 600, 1600, 550, 1600, 600, 1550, 600, 500, 600, 1550, 600, 500, 600, 500, 600, 450, 600, 500, 600, 500, 600, 1550, 600, 500, 600, 1550, 600, 1550, 600, 500, 600, 500, 600, 450, 600, 500, 600, 500, 600, 1550, 600, 500, 600, 500, 550, 1600, 600, 1550, 600, 1600, 550, 1600, 600, 5150}; //制冷 30 中风
unsigned int IR30low[100] = {4450, 4350, 600, 1550, 600, 550, 550, 1550, 650, 1550, 600, 500, 550, 550, 550, 1600, 550, 550, 550, 500, 600, 1550, 600, 500, 600, 500, 550, 1600, 600, 1550, 600, 500, 600, 1550, 600, 1600, 550, 550, 550, 500, 600, 1550, 600, 1600, 550, 1600, 600, 1550, 600, 1600, 600, 500, 550, 1600, 600, 1550, 600, 500, 550, 550, 550, 550, 550, 500, 550, 500, 600, 1600, 550, 550, 550, 1600, 600, 1550, 600, 500, 600, 500, 550, 550, 550, 500, 600, 500, 550, 1600, 600, 500, 550, 550, 550, 1600, 550, 1600, 600, 1550, 600, 1600, 550, 5200}; //制冷 30 低风
int khz = 38; // 38kHz carrier frequency

//DHT12获取温度
float get_temp() {
  float temperature = 30;
  uint8_t bits[5];
  uint8_t checksum;
  do {
    Wire.beginTransmission(0x5C); //DHT12 的地址
    Wire.write(0); //向 DHT12 请求数据
    Wire.endTransmission();
    int bytes = Wire.requestFrom(0x5C, 5);

    for (int i = 0; i < bytes; ++i) {
      bits[i] = Wire.read();
    }
    //humidity = bits[0] + bits[1]*0.1; //获取湿度（此程序不需要）
    temperature = bits[2] + (bits[3] & 0x7F) * 0.1; //获取温度
    if (bits[3] & 0x80) {
      temperature = -temperature;
    }
    checksum = bits[0] + bits[1] + bits[2] + bits[3]; //校验
  } while (bits[4] != checksum);
  return temperature;
}
//红外编码部分结束//

//回归预测未来温度开始//
int interval = 10; //y的数量
float aver_x = 5.5; //从1到interval的平均值，节省时间
float a, b; //回归方程的参数
float y[10] = {};//数量要等于interval

int get_ab(float y[]) {
  float aver_y = 0;
  for (int i = interval - 1; i >= 0; --i) {
    aver_y += y[i];
  }
  aver_y /= interval;

  float b_frac_up = 0;
  for (int i = interval; i; --i) {
    b_frac_up += (i * y[i - 1]);
  }
  b_frac_up -= (interval * aver_x * aver_y);

  float b_frac_down = 0;
  for (int i = interval; i; --i) {
    b_frac_down += (i * i);
  }
  b_frac_down -= (interval * aver_x * aver_x);

  if (b_frac_down) {
    b = b_frac_up / b_frac_down;
    a = aver_y - b * aver_x;
  }
  else return 0;
  return 1;
}

void update_y(float data) { //更新已有数据
  for (int i = 0; i < interval; ++i) {
    y[i] = y[i + 1];
  }
  y[interval - 1] = data;
}

//回归预测未来温度结束//

//setup程序开始//
void setup() {
  Serial.begin(9600);
  Serial.println("Start");
  Wire.begin();
  get_temp(); //清除第一次不准确的数据
  for (int i = 0; i < interval; ++i) { //对y的数据初始化
    y[i] = get_temp();
    delay(1000);
  }
}
//setup程序结束//

//loop程序开始//
int mode = 0;
void loop() {
  // put your main code here, to run repeatedly:
  float future_temp;
  get_ab(y);
  future_temp = b * 20 + a;

  for (int i = 0; i < interval; ++i) { //对y的数据初始化
    Serial.print(y[i], 1);
    Serial.print(',');
  }
  Serial.print("\nTemperature:");
  Serial.println(future_temp, 1);

  if (future_temp <= target_temp+5) {
    if (future_temp >= target_temp-2 && future_temp <= target_temp+2) { //在舒适温度范围内，则不高不低
      if (mode != 25) {
        irsend.sendRaw(IR25mid, 100, khz);
        irsend.sendRaw(IR25mid, 100, khz);//美的空调需要发射两次才行
        Serial.println("send 25");
        mode = 25;
      }
    }
    else if (mode != 30) { //低于舒适温度，则制冷最弱
      irsend.sendRaw(IR30low, 100, khz);
      irsend.sendRaw(IR30low, 100, khz);
      Serial.println("send 30");
      mode = 30;
    }
  }
  else if (mode != 20) { //过高于舒适温度，则尽快降温
    irsend.sendRaw(IR20high, 100, khz); //17℃的风太猛了
    irsend.sendRaw(IR20high, 100, khz);
    Serial.println("send 20");
    mode = 20;
  }
  delay(60000);
  update_y(get_temp());
}
//loop程序结束//

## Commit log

2019-09-05 init
    add README and add an example (auto AC remote control)
    [Untitled Sketch 2.fzz, cup2.stl, shell2.stl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]
2019-09-08 AC remote example
    [Untitled Sketch 2.fzz, cup2.stl, shell2.stl]
